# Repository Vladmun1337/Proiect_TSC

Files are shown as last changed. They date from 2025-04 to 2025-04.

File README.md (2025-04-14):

# Proiect TSC - Openbook e-book reader

Project link: https://ocw.cs.pub.ro/courses/tsc/proiect2025

## Introduction

For this project, I have implemented an open source e-book reader using ***Autodesk Fusion360***.
The architecture is based on an ESP32-C6 low power microcontroller (+ Wi-Fi & Bluetooth).

The display is using e-paper ink. The project supports micro SD reading through the specialized
interface and USB type C charging for a Polymer Lithium-Ion battery, prioritizing performance
and efficient power consumption.

## Diagram
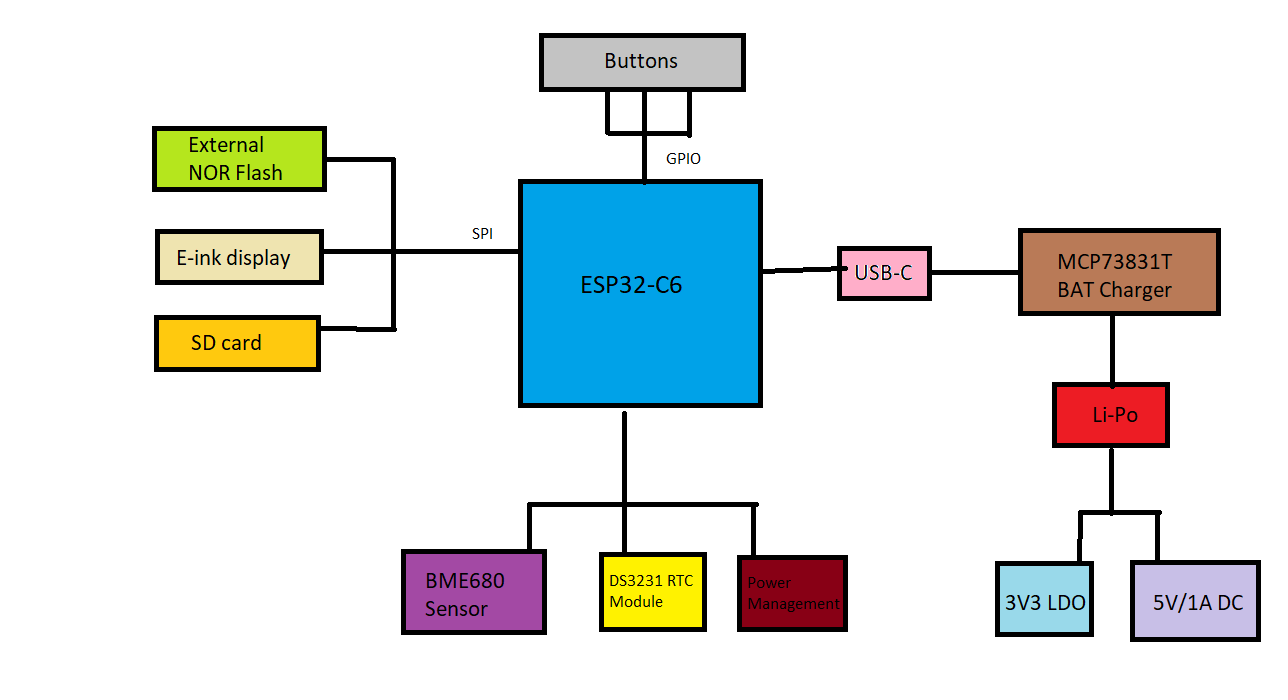
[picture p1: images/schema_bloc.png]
Diagram


## Contents

```
- hardware      -> .brd and .sch files of the board
- mechanical    -> .zip files of project's 3D models (standard and exploded view)
- Manufacturing -> Bill of Materials (BOM), Pick and Place (PnP), Gerber files (.zip)
- images        -> Snapshots of project
- LICENSE
- README.md
```

## Implementation & Workflow

1. **Implementation of the schematic**: The deskassistant library, offered by the lecture, was used. All components placed, linked and tagged
   for easier workflow in the PCB part.
2. **PCB**: Board was trimmed to fit specifications and accomodate busses. Components were then placed, respecting the DRC constraints file and routed
accordingly. Power(0.3mm) and data(0.15mm) lines were routed with different gauges and power routing was done mostly on top layer.
3. **3D Modelling**: All components were researched online and their specific 3D model was imported in the library. For a better grasp of the components used,
check BOM below. After the PCB was succesfully modelled, a battery and e-paper display were sketched from scratch.
4. **Fitting everything**: PCB, battery and display were fitted inside the given encasing and given a photoshoot. :-)

## Bill of Materials (with links)

| Name | Link | Datasheet |
|---|---|---|
| 112A-TAAR-R03 | [Link](https://store.comet.srl.ro/Catalogue/Product/43497/) | [Datasheet](https://store.comet.bg/download-file.php?id=27596) |
| 744043680 | [Link](https://eu.mouser.com/ProductDetail/Wurth-Elektronik/744043680?qs=PGXP4M47uW6VkZq%252BkzjrHA%3D%3D) | [Datasheet](https://www.we-online.com/components/products/datasheet/744043680.pdf) |
| BD5229G-TR | [Link](https://componentsearchengine.com/part-view/BD5229G-TR/ROHM%20Semiconductor) | [Datasheet](https://datasheet.datasheetarchive.com/originals/distributors/Datasheets_SAMA/f2b9741ef86007909f138d561a359946.pdf) |
| Button | [Link](https://industry.panasonic.com/global/en/products/control/switch/light-touch/number/evqpuj02k) | [Datasheet](https://industry.panasonic.com/global/en/downloads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) |
| Capacitor | [Link](https://componentsearchengine.com/part-view/CC0402MRX5R5BB106/YAGEO) | [Datasheet](https://componentsearchengine.com/Datasheets/2/CC0402MRX5R5BB106.pdf) |
| CPH3225A | [Link](https://www.snapeda.com/parts/CPH3225A/Seiko+Instruments/view-part/?ref=eda) | [Datasheet](https://www.snapeda.com/parts/CPH3225A/Seiko%20Instruments/datasheet/) |
| DS3231SN RTC | [Link](https://www.snapeda.com/parts/DS3231SN%23/Analog+Devices/view-part/?ref=eda) | [Datasheet](https://www.snapeda.com/parts/DS3231SN%23/Analog%20Devices/datasheet/) |
| ESP32 WROVER 0805 Capacitor | [Link](https://ro.mouser.com/ProductDetail/KYOCERA-AVX/SD0805S020S1R0?qs=jCA%252BPfw4LHbpkAoSnwrdjw%3D%3D) | [Datasheet](https://ro.mouser.com/datasheet/2/40/schottky-3165252.pdf) |
| ESP32 WROVER BME680 Sensor | [Link](https://www.snapeda.com/parts/BME680/Bosch/view-part/?welcome=home) | [Datasheet](https://www.snapeda.com/parts/BME680/Bosch%20Sensortec/datasheet/) |
| ESP32 WROVER MCP73831 | [Link](https://eu.mouser.com/ProductDetail/Microchip-Technology/MCP73831T-2ACI-OT?qs=yUQqVecv4qvbBQBGbHx0Mw%3D%3D) | [Datasheet](https://eu.mouser.com/datasheet/2/268/MCP73831_Family_Data_Sheet_DS20001984H-3441711.pdf) |
| ESP32 WROVER P-Channel MOSFET | [Link](https://componentsearchengine.com/part-view/DMG2305UX-7/Diodes%20Incorporated) | [Datasheet](https://www.diodes.com//assets/Datasheets/DMG2305UX.pdf) |
| ESP32-C6 WROOM-1-N8 | [Link](https://www.snapeda.com/parts/ESP32-C6-WROOM-1-N8/Espressif+Systems/view-part/?ref=eda) | [Datasheet](https://www.snapeda.com/parts/ESP32-C6-WROOM-1-N8/Espressif%20Systems/datasheet/) |
| ESP32C6 Varistor 1812 | [Link](https://ro.mouser.com/ProductDetail/EPCOS-TDK/B72520T0350K062?qs=dEfas%2FXlABIszF52uu7vrg%3D%3D) | [Datasheet](https://www.tdk-electronics.tdk.com/inf/75/db/CTVS_14/Surge_protection_series.pdf) |
| FH34SRJ-24S-0.5SH Connector | [Link](https://componentsearchengine.com/part-view/FH34SRJ-24S-0.5SH(99)/Hirose) | [Datasheet](https://www.hirose.com/en/product/document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) |
| LED 0603 | [Link](https://www.snapeda.com/parts/KP-1608SURCK/Kingbright/view-part/?ref=search&t=LED%200603) | [Datasheet](https://www.snapeda.com/parts/KP-1608SURCK/Kingbright/datasheet/) |
| LTSPICE Resistor 0402 | [Link](https://componentsearchengine.com/part-view/R0402%201%25%20100%20K%20(RC0402FR-07100KL)/YAGEO) | [Datasheet](https://www.yageo.com/upload/media/product/products/datasheet/rchip/PYu-RC_Group_51_RoHS_L_12.pdf) |
| MAX17048G+T10 | [Link](https://www.snapeda.com/parts/MAX17048G+T10/Analog+Devices/view-part/?ref=eda) | [Datasheet](https://www.snapeda.com/parts/MAX17048G+T10/Analog%20Devices/datasheet/) |
| MBR0530 Schottky | [Link](https://www.snapeda.com/parts/MBR0530/Onsemi/view-part/?ref=eda) | [Datasheet](https://www.snapeda.com/parts/MBR0530/ON%20Semiconductor/datasheet/) |
| PGB1010603MR | [Link](https://www.snapeda.com/parts/PGB1010603MR/Littelfuse/view-part/?ref=eda) | [Datasheet](https://www.snapeda.com/parts/PGB1010603MR/Littelfuse%20Inc./datasheet/) |
| QWIIC Connector | [Link](https://eu.mouser.com/ProductDetail/Adafruit/4208?qs=PzGy0jfpSMtbScLbr0L5dw%3D%3D) | [Datasheet](https://www.youtube.com/watch?v=dQw4w9WgXcQ) |
| RCL CPOL 3528 | [Link](https://www.snapeda.com/parts/TAJB475K025RNJ/AVX/view-part/?ref=dk&t=capacitor%203528&con_ref=None) | [Datasheet](https://s3.amazonaws.com/snapeda/datasheet/TAJB475K025RNJ_AVX.pdf) |
| SI1308EDL-T1-GE3 MOSFET | [Link](https://www.snapeda.com/parts/SI1308EDL-T1-GE3/Vishay+Siliconix/view-part/?ref=eda) | [Datasheet](https://www.youtube.com/watch?v=dQw4w9WgXcQ) |
| SJ | [Link](https://grabcad.com/library/solder-jumpers-1) | [Datasheet](https://www.youtube.com/watch?v=dQw4w9WgXcQ) |
| TPTP20R | [Link](https://easyeda.com/component/7524403feb2642ac9f9f26dfb93ceacf) | [Datasheet](https://easyeda.com/component/7524403feb2642ac9f9f26dfb93ceacf) |
| USB4110-GF-A USB | [Link](https://componentsearchengine.com/part-view/USB4110-GF-A/GCT%20(GLOBAL%20CONNECTOR%20TECHNOLOGY)) | [Datasheet](https://gct.co/files/drawings/usb4110.pdf) |
| USBLC6-2SC6Y USB | [Link](https://www.snapeda.com/parts/USBLC6-2SC6Y/STMicroelectronics/view-part/?ref=eda) | [Datasheet](https://www.snapeda.com/parts/USBLC6-2SC6Y/STMicroelectronics/datasheet/) |
| W25Q512JVEIQ Flash | [Link](https://www.snapeda.com/parts/W25Q512JVEIQ/Winbond+Electronics/view-part/?ref=eda) | [Datasheet](https://www.snapeda.com/parts/W25Q512JVEIQ/Winbond%20Electronics/datasheet/) |
| XC6220A331MR-G Voltage Regulator | [Link](https://componentsearchengine.com/part-view/XC6220A331MR-G/Torex) | [Datasheet](https://product.torexsemi.com/system/files/series/xc6220.pdf) |

## ESP32-C6 Pinout

An overview of how the ESP32-C6 pins are assigned within the system, grouped by function.

### Power
- **3V3 (Pin 2 & Top Right):** 3.3V supply for ESP32 and peripherals.
- **GND (Bottom Right):** Common ground.

### Boot and Reset
- **GPIO8 (Pin 15):** Boot mode selection, pulled low via 10KΩ.
- **RESET (Pin 3):** Manual reset input.

### SPI (E-Paper Display, SD Card, Flash)
- **MISO (Pin 27)**
- **MOSI (Pin 10)**
- **SCK (Pin 7)**
- **SS_SD (Pin 4):** Chip Select for SD card or other SPI device.
- **EPD_CS (Pin 11):** Chip Select for E-Paper Display.
- **FLASH_CS (Pin 12):** Chip Select for NOR Flash.

### E-Paper Display Control
- **EPD_BUSY (Pin 26)**
- **EPD_DC (Pin 5)**
- **EPD_RST (Pin 21)**
- **EPD_3V3_C (Pin 19):** Likely power enable/control.

### I2C (RTC & Sensors)
- **SDA (Pin 20)**
- **SCL (Pin 21)**
- **I2C_PW (Pin 18):** Power enable for I2C devices.
- **INT_RTC (Pin 8):** RTC interrupt.
- **RTC_RST (Pin 16)**

### USB
- **USB_D- (Pin 13)**
- **USB_D+ (Pin 14)**

### UART
- **TX (Pin 25)**
- **RX (Pin 24)**

### Other GPIO
- **IO_CHANGE (Pin 23):** Interrupt or status input/output.

## Total Power Consumption Overview

In a typical operating scenario—where the ESP32-C6 remains active with Wi-Fi enabled, the e-paper display refreshes every 10 seconds, and the BME688 sensor continuously collects environmental data—the estimated current draw for the system is as follows:

| Component | Estimated Consumption (mA) |
|---|---|
| ESP32-C6 (Wi-Fi enabled) | 200 mA |
| E-Paper Display (during update) | 40 mA |
| BME688 Sensor (continuous use) | 2 mA |
| Real-Time Clock (RTC) Module | 2 mA |
| SD Card (active use) | 12 mA |
| External NOR Flash Memory | 25 mA |

### Typical Total Current Draw

**Total: 281 mA**

This estimate represents a high-activity configuration. In lower-power modes (e.g., sleep or deep sleep), consumption can be significantly reduced.

## Conclusions

This project was very exciting for me. A lot of difficulties came from me having little to no prior experience with the autodesk suite, but everything sorted
itself out. I feel that I could get a good grasp of what working in the hardware and product industry means and am open to work on more other such projects! :-)

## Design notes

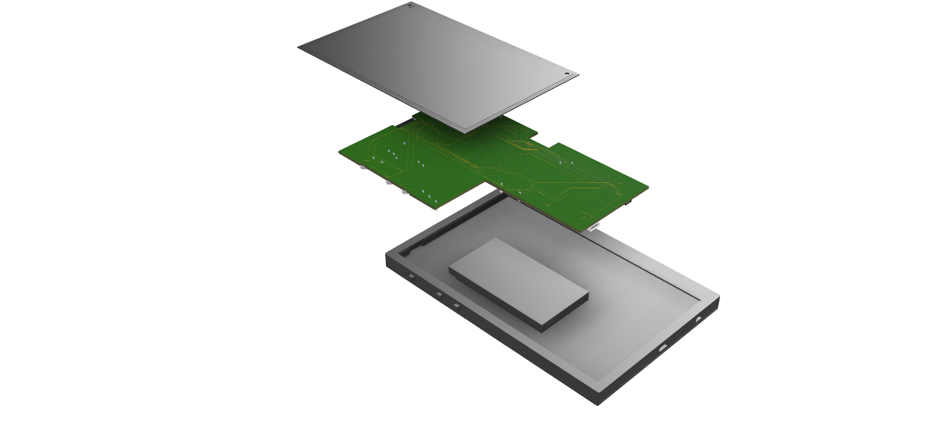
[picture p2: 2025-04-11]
images/openbook_exploded_full.png

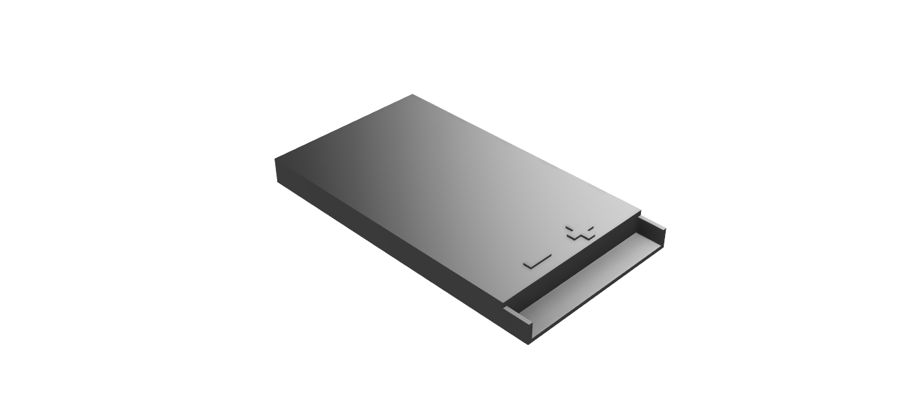
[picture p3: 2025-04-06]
images/battery.png

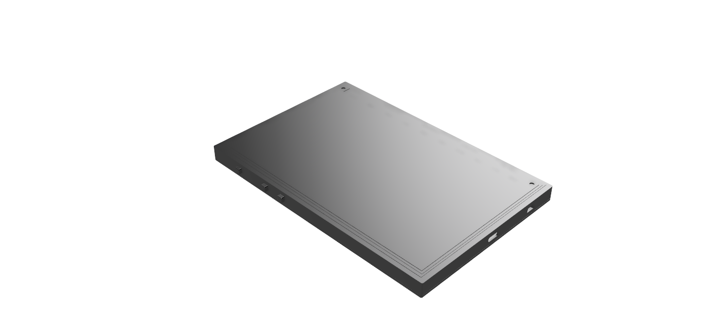
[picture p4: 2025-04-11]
images/openbook_full_3D.png

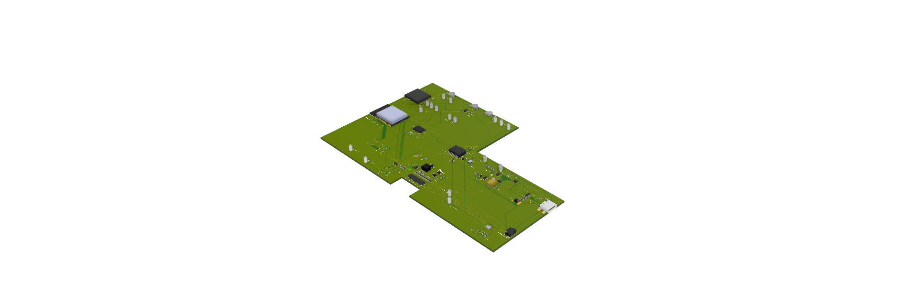
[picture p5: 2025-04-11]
images/3D_Board.png

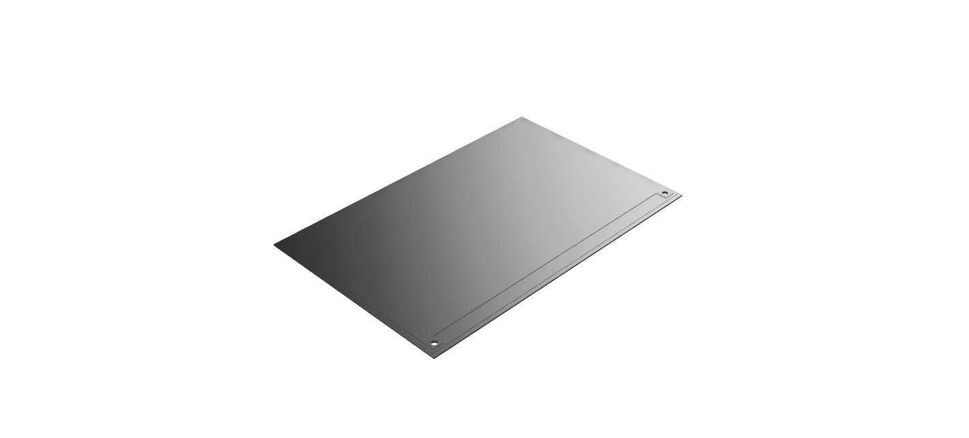
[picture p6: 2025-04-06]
images/display.png

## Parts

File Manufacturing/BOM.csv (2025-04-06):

Qty | Value | Device | Package | Parts | Description | ARROW_PART_NUMBER | ARROW_PRICE-STOCK | AVAILABILITY | CENTROID_NOT_SPECIFIED | CHECK_PRICES | COPYRIGHT | DATASHEET | DESCRIPTION | DIGIKEY_DESCRIPTION | DIGIKEY_PART_NUMBER | HEIGHT | LEAD_FREE | MANUFACTURER_NAME | MANUFACTURER_PART_NUMBER | MF | MFR_NAME | MOUSER_PART_NUMBER | MOUSER_PRICE-STOCK | MOUSER_TESTING_PART_NUMBER | MOUSER_TESTING_PRICE-STOCK | MP | MPN | PACKAGE | POPULARITY | PREFIX | PRICE | PROD_ID | PURCHASE-URL | ROHS | SNAPEDA_LINK | SPICEMODEL | SPICEPREFIX | TEMPERATURE_RANGE_HIGH | TEMPERATURE_RANGE_LOW | TP_SIGNAL_NAME | VALUE
1 |  | ADAFRUIT_LEDCHIP-LED0603 | ADAFRUIT_CHIP-LED0603 | LED1 | LED
1 |  | SJ | SJ | SJ1 | SMD solder JUMPER |  |  |  |  |  |  |  |  |  |  |  |  |  |  |  |  |  |  |  |  |  |  |  | 3
1 | 0.1uF/50V | EAGLE-LTSPICE_CC0402 | EAGLE-LTSPICE_C0402 | C13 | CAPACITOR, European symbol |  |  |  |  |  |  |  |  |  |  |  |  |  |  |  |  |  |  |  |  |  |  |  |  |  |  |  |  |  |  | NONE | C
1 | 0.47 | ESP32_WROVER_EAGLE-LTSPICE_RR0402 | ESP32_WROVER_EAGLE-LTSPICE_R0402 | R9 | RESISTOR, European symbol |  |  |  |  |  |  |  |  |  |  |  |  |  |  |  |  |  |  |  |  |  |  |  |  |  |  |  |  |  |  | NONE | R
1 | 100K | ESP32_WROVER_EAGLE-LTSPICE_RR0402 | ESP32_WROVER_EAGLE-LTSPICE_R0402 | R4 | RESISTOR, European symbol |  |  |  |  |  |  |  |  |  |  |  |  |  |  |  |  |  |  |  |  |  |  |  |  |  |  |  |  |  |  | NONE | R
8 | 100nF | EAGLE-LTSPICE_CC0402 | EAGLE-LTSPICE_C0402 | C1, C6, C21, C22, C23, C25, C27, C28 | CAPACITOR, European symbol |  |  |  |  |  |  |  |  |  |  |  |  |  |  |  |  |  |  |  |  |  |  |  |  |  |  |  |  |  |  | NONE | C
1 | 100uF | RCL_CPOL-EUCT3528 | RCL_CT3528 | C4 | POLARIZED CAPACITOR, European symbol |  |  |  |  |  |  |  |  |  |  |  |  |  |  |  |  |  |  |  |  |  |  |  | 0 |  |  |  |  |  |  |  | C
16 | 10K | ESP32_WROVER_EAGLE-LTSPICE_RR0402 | ESP32_WROVER_EAGLE-LTSPICE_R0402 | R6, R7, R8, R12, R13, R15, R16, R17, R18, R19, R26, R27, R28, R29, R30, R31 | RESISTOR, European symbol |  |  |  |  |  |  |  |  |  |  |  |  |  |  |  |  |  |  |  |  |  |  |  |  |  |  |  |  |  |  | NONE | R
1 | 10uF | EAGLE-LTSPICE_CC0402 | EAGLE-LTSPICE_C0402 | C8 | CAPACITOR, European symbol |  |  |  |  |  |  |  |  |  |  |  |  |  |  |  |  |  |  |  |  |  |  |  |  |  |  |  |  |  |  | NONE | C
1 | 112A-TAAR-R03_ATTEND | 112A-TAAR-R03_ATTEND | 112ATAARR03ATTEND | J2 | Micro SD Card Socket, Push-Push Type, Top Mount, SMT, H=1.83mm, 10u |  |  |  |  |  |  |  | Micro SD Card Socket | Push-Push Type | Top Mount | SMT | H=1.83mm | 10u |  |  | 1.9mm |  | ATTEND | 112A-TAAR-R03 ATTEND
1 | 15 | ESP32_WROVER_EAGLE-LTSPICE_RR0402 | ESP32_WROVER_EAGLE-LTSPICE_R0402 | R14 | RESISTOR, European symbol |  |  |  |  |  |  |  |  |  |  |  |  |  |  |  |  |  |  |  |  |  |  |  |  |  |  |  |  |  |  | NONE | R
1 | 1uF | EAGLE-LTSPICE_CC0402 | EAGLE-LTSPICE_C0402 | C26 | CAPACITOR, European symbol |  |  |  |  |  |  |  |  |  |  |  |  |  |  |  |  |  |  |  |  |  |  |  |  |  |  |  |  |  |  | NONE | C
9 | 1uF/50V | EAGLE-LTSPICE_CC0402 | EAGLE-LTSPICE_C0402 | C11, C12, C14, C15, C16, C17, C18, C19, C20 | CAPACITOR, European symbol |  |  |  |  |  |  |  |  |  |  |  |  |  |  |  |  |  |  |  |  |  |  |  |  |  |  |  |  |  |  | NONE | C
1 | 2.2 | ESP32_WROVER_EAGLE-LTSPICE_RR0402 | ESP32_WROVER_EAGLE-LTSPICE_R0402 | R5 | RESISTOR, European symbol |  |  |  |  |  |  |  |  |  |  |  |  |  |  |  |  |  |  |  |  |  |  |  |  |  |  |  |  |  |  | NONE | R
1 | 200 | ESP32_WROVER_EAGLE-LTSPICE_RR0402 | ESP32_WROVER_EAGLE-LTSPICE_R0402 | R10 | RESISTOR, European symbol |  |  |  |  |  |  |  |  |  |  |  |  |  |  |  |  |  |  |  |  |  |  |  |  |  |  |  |  |  |  | NONE | R
3 | 20V/4.2A/52mO/1.4W | ESP32_WROVER_SPARKFUN-DISCRETESEMI_MOSFET_PCH-DMG2305UX-7 | ESP32_WROVER_SPARKFUN-DISCRETESEMI_SOT23-3 | Q1, Q2, Q3 | P-channel MOSFETs |  |  |  |  |  |  |  |  |  |  |  |  |  |  |  |  |  |  |  |  |  |  |  |  |  |  | TRAN-14388 |  |  |  |  |  |  |  |  | 20V/4.2A/52mO/1.4W
1 | 2K | ESP32_WROVER_EAGLE-LTSPICE_RR0402 | ESP32_WROVER_EAGLE-LTSPICE_R0402 | R11 | RESISTOR, European symbol |  |  |  |  |  |  |  |  |  |  |  |  |  |  |  |  |  |  |  |  |  |  |  |  |  |  |  |  |  |  | NONE | R
5 | 4.7uF | EAGLE-LTSPICE_CC0402 | EAGLE-LTSPICE_C0402 | C2, C3, C5, C9, C10 | CAPACITOR, European symbol |  |  |  |  |  |  |  |  |  |  |  |  |  |  |  |  |  |  |  |  |  |  |  |  |  |  |  |  |  |  | NONE | C
1 | 4.7uF/25V | EAGLE-LTSPICE_CC0402 | EAGLE-LTSPICE_C0402 | C7 | CAPACITOR, European symbol |  |  |  |  |  |  |  |  |  |  |  |  |  |  |  |  |  |  |  |  |  |  |  |  |  |  |  |  |  |  | NONE | C
2 | 5k1 | ESP32_WROVER_EAGLE-LTSPICE_RR0402 | ESP32_WROVER_EAGLE-LTSPICE_R0402 | R1, R3 | RESISTOR, European symbol |  |  |  |  |  |  |  |  |  |  |  |  |  |  |  |  |  |  |  |  |  |  |  |  |  |  |  |  |  |  | NONE | R
1 | 68uH | 744043680IND_4828-WE-TPC_WRE | IND_4828-WE-TPC_WRE | L1 |  |  |  |  |  |  | Copyright (C) 2024 Ultra Librarian. All rights reserved. |  |  |  |  |  |  |  | 744043680 |  | Wurth Electronics
1 | BD5229G-TR | BD5229G-TR | SOT95P280X125-5N | IC2 | Voltage Detector with Adjustable Delay Time: CMOS processes are utilized to develop high precision, low current consumption CMOS reset ICs that allow arbitrary setting of the delay time. The extensive lineup includes both Nch Open Drain and CMOS output types in a wide range of detection voltages (from 2.3V to 6.0V, in 0.1V steps), enabling selection of the ideal solution based on customer requirements. In addition, the entire series is of course both lead-free and RoHS-compliant. |  |  |  |  |  |  |  | Voltage Detector with Adjustable Delay Time: CMOS processes are utilized to develop high precision | low current consumption CMOS reset ICs that allow arbitrary setting of the delay time. The extensive lineup includes both Nch Open Drain and CMOS output types in a wide range of detection voltages (from 2.3V to 6.0V | in 0.1V steps) | enabling selection of the ideal solution based on customer requirements. In addition | the entire series is of course both lead-free and RoHS-compliant. |  |  | 1.25mm |  | ROHM Semiconductor | BD5229G-TR |  |  | 755-BD5229G-TR | https://www.mouser.co.uk/ProductDetail/ROHM-Semiconductor/BD5229G-TR?qs=4kLU8WoGk0vvnhrrYwdszw%3D%3D
3 | BUTTON_CUSYOMV1 | BUTTON_CUSYOMV1 | MYBUTTON | U$1, U$2, U$3
1 | CPH3225A | CPH3225A | CAPCP3225X100N | C24 | Cap 0.011F 3.3V 1210 Flat Check availability |  |  | Not in stock |  | https://www.snapeda.com/parts/CPH3225A/Seiko+Instruments/view-part/?ref=eda |  |  | 11 mF (EDLC) Supercapacitor 3.3 V 1210 (3225 Metric) - - |  |  |  |  |  |  | Seiko Instruments |  |  |  |  |  | CPH3225A |  | 1210 Seiko |  |  | None |  | https://www.snapeda.com/api/url_track_click_mouser/?unipart_id=562593&manufacturer=Seiko Instruments&part_name=CPH3225A&search_term=None |  | https://www.snapeda.com/parts/CPH3225A/Seiko+Instruments/view-part/?ref=snap
1 | DS3231SN# | DS3231SN# | SOIC127P1032X265-16N | U6 | Real Time Clock Serial 16-Pin SOIC W T/R Check availability |  |  | In Stock |  | https://www.snapeda.com/parts/DS3231SN%23/Analog+Devices/view-part/?ref=eda |  |  | Extremely Accurate I²C-Integrated RTC/TCXO/Crystal |  |  |  |  |  |  | Analog Devices |  |  |  |  |  | DS3231SN# |  | SOIC-16 Maxim |  |  | None |  | https://www.snapeda.com/api/url_track_click_mouser/?unipart_id=99048&manufacturer=Analog Devices&part_name=DS3231SN#&search_term=None |  | https://www.snapeda.com/parts/DS3231SN%23/Analog+Devices/view-part/?ref=snap
1 | ESP32-C6-WROOM-1-N8 | ESP32-C6-WROOM-1-N8 | XCVR_ESP32-C6-WROOM-1-N8 | U1 | Check availability |  |  | In Stock |  | https://www.snapeda.com/parts/ESP32-C6-WROOM-1-N8/Espressif+Systems/view-part/?ref=eda |  |  | Multiprotocol Modules ESP32-C6 module | Wi-Fi 6 in 2.4 GHz band | Bluetooth 5 | Zigbee 3.0 and Thread. ESP34-WROOM Compatible - ENGINEERING SAMPLE |  |  |  |  |  |  | Espressif Systems |  |  |  |  |  | ESP32-C6-WROOM-1-N8 |  | None |  |  | None |  |  |  | https://www.snapeda.com/parts/ESP32-C6-WROOM-1-N8/Espressif+Systems/view-part/?ref=snap
1 | ESP32C6_VARISTORCN1812 | ESP32C6_VARISTORCN1812 | ESP32C6_VARISTOR_CT/CN1812 | R2 | VARISTOR |  |  |  |  |  |  |  |  |  |  |  |  |  |  |  |  |  |  |  |  |  |  |  | 0
2 | ESP32_WROVER_AVX---SD0805S020S1R0_AVX_SD0805S020S1R0_0_0AVX_SD0805S020S1R0_0_0 | ESP32_WROVER_AVX---SD0805S020S1R0_AVX_SD0805S020S1R0_0_0AVX_SD0805S020S1R0_0_0 | ESP32_WROVER_AVX---SD0805S020S1R0_AVX_SD0805S020S1R0_0 | D2, D6 | Schottky Barrier Rectifier Diode |  |  |  | No |  |  | http://datasheets.avx.com/schottky.pdf |  | DIODE SCHOTTKY 20V 1A 0805 | 478-7800-1-ND |  | yes |  |  | AVX |  | 581-SD0805S020S1R0 |  |  |  |  |  | 0805 (2012 metric) |  | D |  |  |  | yes |  |  |  | +125°C | -55°C
1 | ESP32_WROVER_BME680_BME680 | ESP32_WROVER_BME680_BME680 | ESP32_WROVER_BME680_PSON80P300X300X100-8N | U5 | Integrated Environmental Unit |  |  | Unavailable |  |  |  |  | Integrated Environmental Unit |  |  |  |  |  |  | Bosch Sensortec |  |  |  |  |  | BME680 |  | LGA-8 Bosch Tools |  |  | None
1 | ESP32_WROVER_SPARKFUN-IC-POWER_MCP73831 | ESP32_WROVER_SPARKFUN-IC-POWER_MCP73831 | ESP32_WROVER_SPARKFUN-IC-POWER_SOT23-5 | U4 | MCP73831T Li-Ion, Li-Pol Controller |  |  |  |  |  |  |  |  |  |  |  |  |  |  |  |  |  |  |  |  |  |  |  |  |  |  | IC-09995
1 | FH34SRJ-24S-0.5SH_99_ | FH34SRJ-24S-0.5SH_99_ | FH34SRJ24S05SH99 | J4 | (0.50mm) Surface Mount, Right Angle |  |  |  |  |  |  |  | 24 Position FFC | FPC Connector Contacts | (0.50mm) Surface Mount | Right Angle |  |  | 1.1mm |  | Hirose | FH34SRJ-24S-0.5SH(99) |  |  | 798-FH34SRJ24S05SH99 | https://www.mouser.co.uk/ProductDetail/Hirose-Connector/FH34SRJ-24S-0.5SH99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
1 | MAX17048G+T10 | MAX17048G+T10 | SON50P200X200X80-9N | U2 | Check availability |  |  | In Stock |  | https://www.snapeda.com/parts/MAX17048G+T10/Analog+Devices/view-part/?ref=eda |  |  | 3µA 1-Cell/2-Cell Fuel Gauge with ModelGauge |  |  |  |  |  |  | Analog Devices |  |  |  |  |  | MAX17048G+T10 |  | TDFN-8 Maxim |  |  | None |  | https://www.snapeda.com/api/url_track_click_mouser/?unipart_id=329239&manufacturer=Analog Devices&part_name=MAX17048G+T10&search_term=None |  | https://www.snapeda.com/parts/MAX17048G+T10/Analog+Devices/view-part/?ref=snap
3 | MBR0530 | MBR0530 | SOD3716X135N | D3, D4, D5 | ON SEMICONDUCTOR - MBR0530 - DIODE, SCHOTTKY, 0.5A, 30V, SOD-123 |  |  | In Stock |  | https://www.snapeda.com/parts/MBR0530/Onsemi/view-part/?ref=eda |  |  | Diode Schottky 30 V 500mA Surface Mount SOD-123 |  |  |  |  |  |  | ON Semiconductor |  |  |  |  |  | MBR0530 |  | SOD-123-2 ON Semiconductor |  |  | None |  | https://www.snapeda.com/api/url_track_click_mouser/?unipart_id=179458&manufacturer=ON Semiconductor&part_name=MBR0530&search_term=None |  | https://www.snapeda.com/parts/MBR0530/Onsemi/view-part/?ref=snap
6 | PGB1010603MR | PGB1010603MR | DIOC1608X36N | D7, D8, D9, D10, D11, D12 | Check availability |  |  | In Stock |  | https://www.snapeda.com/parts/PGB1010603MR/Littelfuse/view-part/?ref=eda |  |  | 150V (Typ) Clamp - Ipp Tvs Diode Surface Mount 0603 (1608 Metric) |  |  |  |  |  |  | Littelfuse Inc. |  |  |  |  |  | PGB1010603MR |  | 0603 Littelfuse Inc. |  |  | None |  | https://www.snapeda.com/api/url_track_click_mouser/?unipart_id=5659453&manufacturer=Littelfuse Inc.&part_name=PGB1010603MR&search_term=None |  | https://www.snapeda.com/parts/PGB1010603MR/Littelfuse/view-part/?ref=snap
1 | QWIIC_RIGHT_ANGLE | QWIIC_CONNECTORJS-1MM | JST04_1MM_RA | J3 | SparkFun I2C Standard Qwiic Connector |  |  |  |  |  |  |  |  |  |  |  |  |  |  |  |  |  |  |  |  |  |  |  |  |  |  | CONN-13694 |  |  |  |  |  |  |  |  | QWIIC_RIGHT_ANGLE
1 | SAMACSYS_PARTS_USB4110-GF-A | SAMACSYS_PARTS_USB4110-GF-A | SAMACSYS_PARTS_USB4110GFA | J1 | CONN USB 2.0 TYPE-C R/A SMT |  |  |  |  |  |  |  | CONN USB 2.0 TYPE-C R/A SMT |  |  | 3.26mm |  | GCT (GLOBAL CONNECTOR TECHNOLOGY) | USB4110-GF-A |  |  | 640-USB4110-GF-A | https://www.mouser.co.uk/ProductDetail/GCT/USB4110-GF-A?qs=KUoIvG%2F9IlYiZvIXQjyJeA%3D%3D
17 | TPTP20R | TPTP20R | TP20R | TP1, TP2, TP3, TP4, TP5, TP6, TP7, TP8, TP9, TP10, TP11, TP12, TP13, TP14, TP15, TP16, TP17 | Test pad |  |  |  |  |  |  |  |  |  |  |  |  |  |  |  |  |  |  |  |  |  |  |  | 2
1 | USBLC6-2SC6Y | USBLC6-2SC6Y | SOT95P280X145-6N | D1 | Low Cap. ESD Protection Auto SOT-23-6 STMicroelectronics USBLC6-2SC6Y, Dual Uni-Directional TVS Diode Array, 6-Pin SOT-23 |  |  | In Stock |  | https://www.snapeda.com/parts/USBLC6-2SC6Y/STMicroelectronics/view-part/?ref=eda |  |  | 17V Clamp 5A (8/20µs) Ipp Tvs Diode Surface Mount SOT-23-6 |  |  |  |  |  |  | STMicroelectronics |  |  |  |  |  | USBLC6-2SC6Y |  | SOT-23-6 STMicroelectronics |  |  | None |  |  |  | https://www.snapeda.com/parts/USBLC6-2SC6Y/STMicroelectronics/view-part/?ref=snap
1 | W25Q512JVEIQ | W25Q512JVEIQ | SON127P600X800X80-9N | U3 | Check availability |  |  | In Stock |  | https://www.snapeda.com/parts/W25Q512JVEIQ/Winbond+Electronics/view-part/?ref=eda |  |  | FLASH - NOR Memory IC 512Mb (64M x 8) SPI - Quad I/O 133 MHz 8-WSON (8x6) |  |  |  |  |  |  | Winbond Electronics |  |  |  |  |  | W25Q512JVEIQ |  | Package |  |  | None |  |  |  | https://www.snapeda.com/parts/W25Q512JVEIQ/Winbond+Electronics/view-part/?ref=snap
1 | XC6220A331MR-G | XC6220A331MR-G | SOT95P280X120-5N | IC1 | LDO Voltage Regulators |  |  |  |  |  |  |  | LDO Voltage Regulators |  |  | 1.2mm |  | Torex | XC6220A331MR-G |  |  | 865-XC6220A331MR-G | https://www.mouser.co.uk/ProductDetail/Torex-Semiconductor/XC6220A331MR-G?qs=AsjdqWjXhJ8ZSWznL1J0gg%3D%3D

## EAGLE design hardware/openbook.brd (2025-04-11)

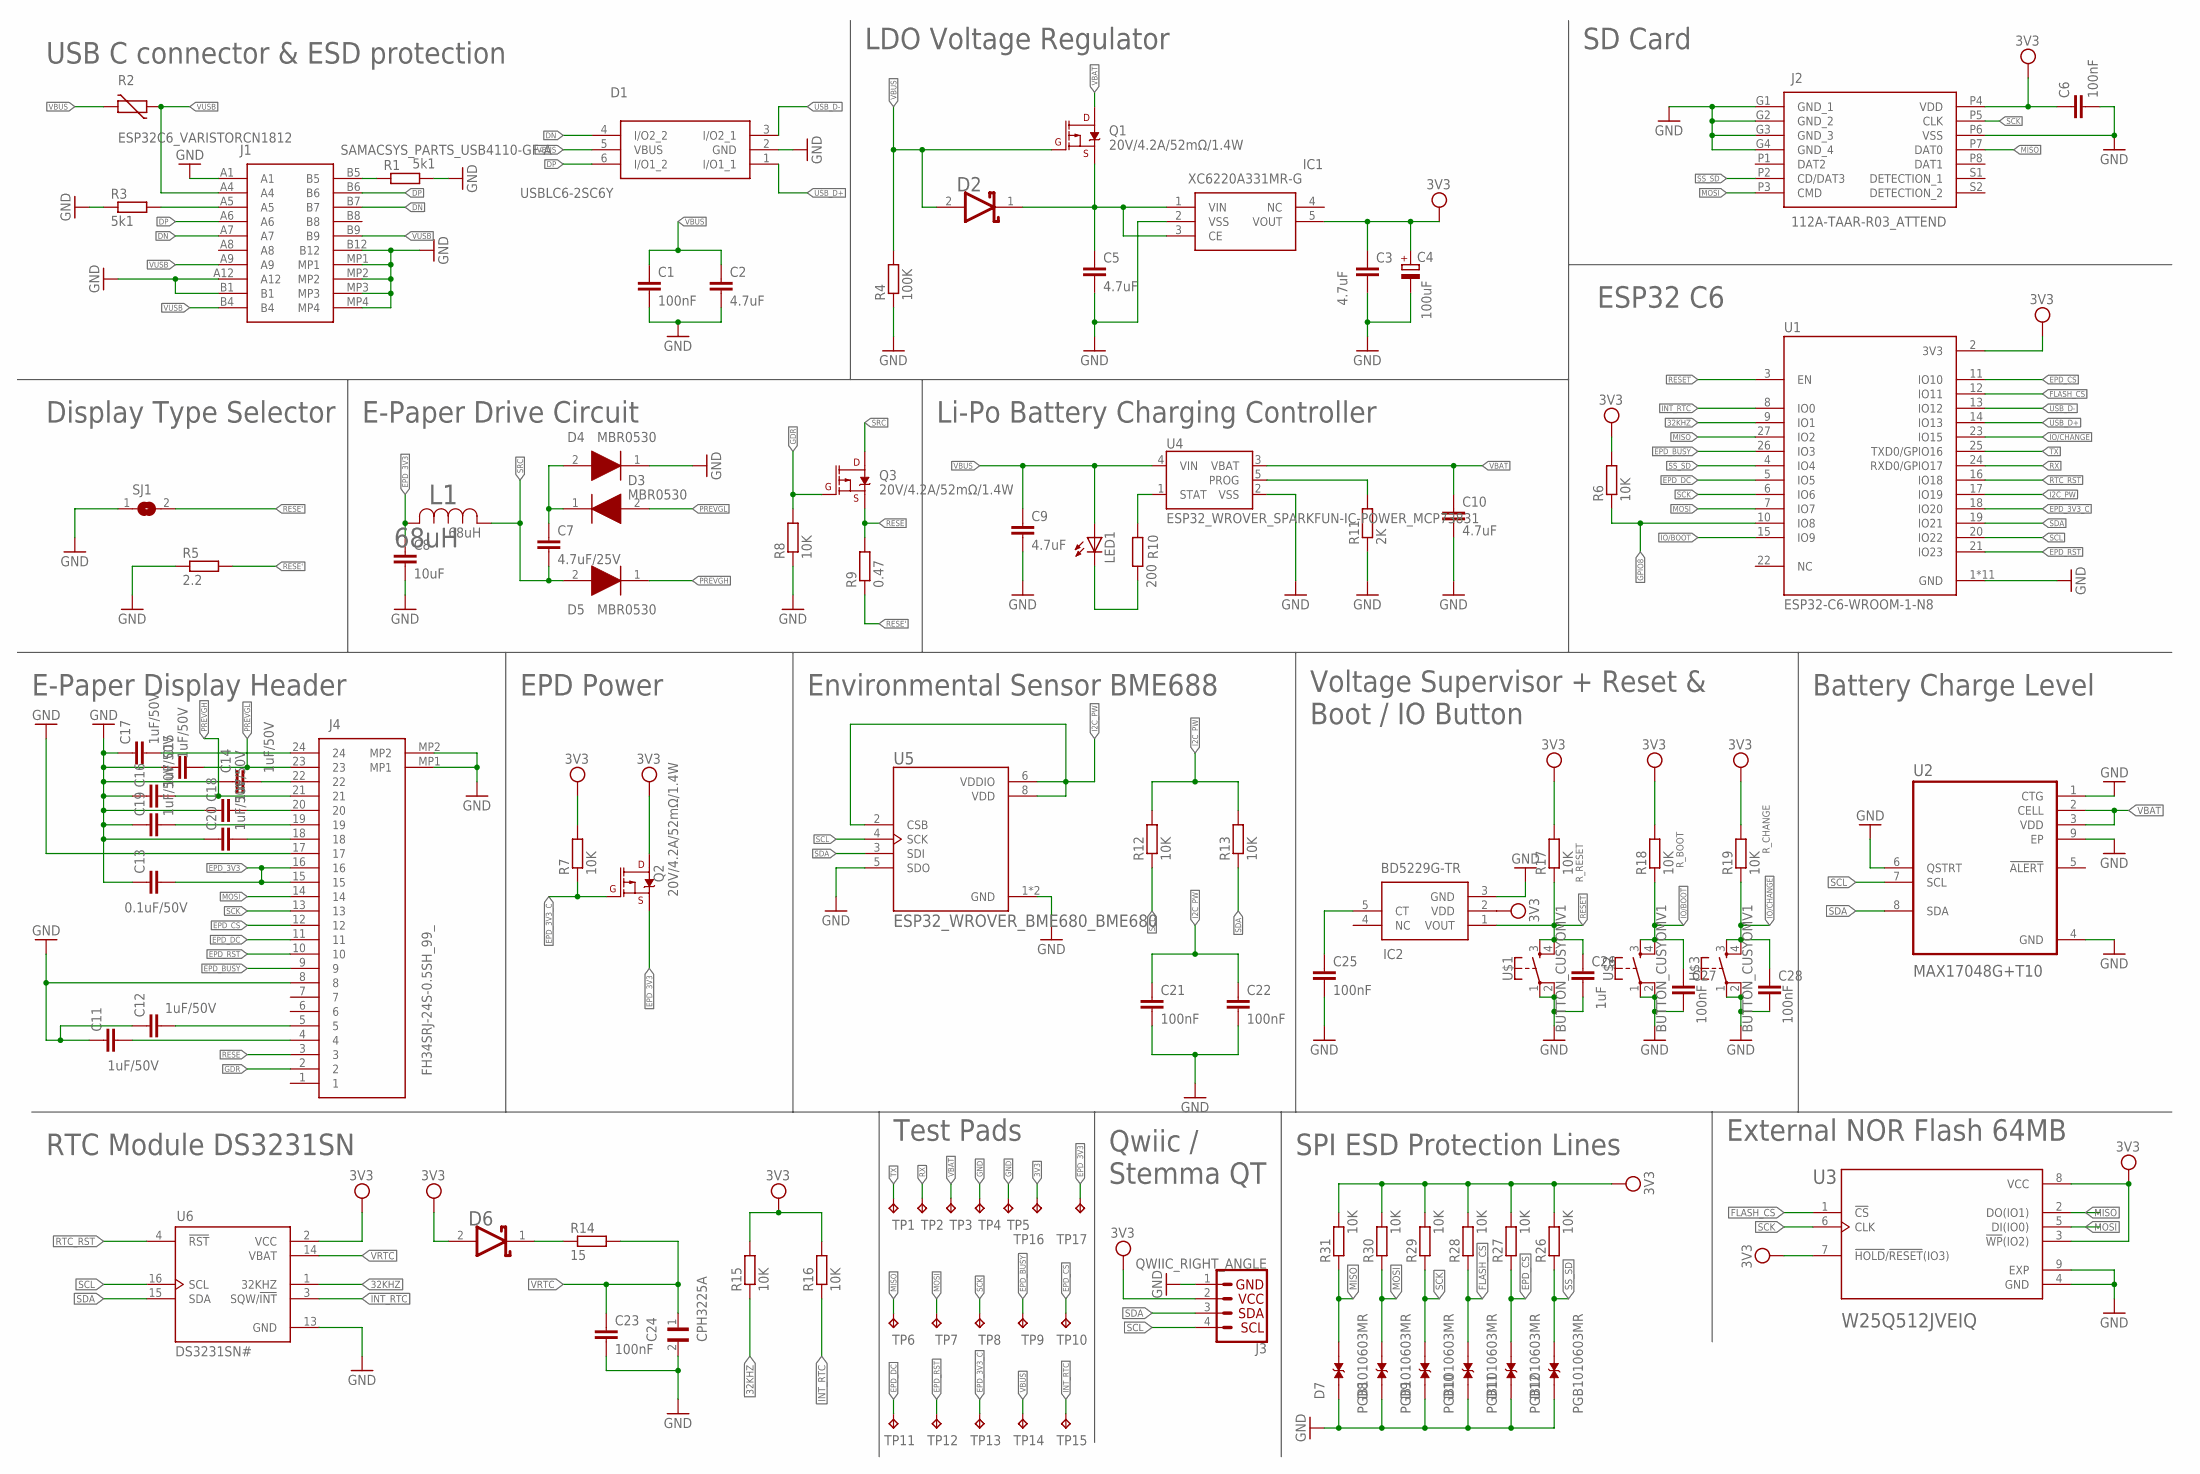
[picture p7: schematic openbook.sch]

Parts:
C1, C6, C21, C22, C23, C25, C27, C28: 100nF; EAGLE-LTSPICE_C0402
C2, C3, C5, C9, C10: 4.7uF; EAGLE-LTSPICE_C0402
C4: 100uF; RCL_CT3528
C7: 4.7uF/25V; EAGLE-LTSPICE_C0402
C8: 10uF; EAGLE-LTSPICE_C0402
C11, C12, C14, C15, C16, C17, C18, C19, C20: 1uF/50V; EAGLE-LTSPICE_C0402
C13: 0.1uF/50V; EAGLE-LTSPICE_C0402
C24: CPH3225A; CAPCP3225X100N
C26: 1uF; EAGLE-LTSPICE_C0402
D1: USBLC6-2SC6Y; SOT95P280X145-6N
D2, D6: ESP32_WROVER_AVX---SD0805S020S1R0_AVX_SD0805S020S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; ESP32_WROVER_AVX---SD0805S020S1R0_AVX_SD0805S020S1R0_0
D3, D4, D5: MBR0530; SOD3716X135N
D7, D8, D9, D10, D11, D12: PGB1010603MR; DIOC1608X36N
IC1: XC6220A331MR-G; SOT95P280X120-5N
IC2: BD5229G-TR; SOT95P280X125-5N
J1: SAMACSYS_PARTS_USB4110-GF-A; SAMACSYS_PARTS_USB4110GFA
J2: 112A-TAAR-R03_ATTEND; 112ATAARR03ATTEND
J3: QWIIC_RIGHT_ANGLE; JST04_1MM_RA
J4: FH34SRJ-24S-0.5SH_99_; FH34SRJ24S05SH99
L1: 68uH; IND_4828-WE-TPC_WRE
LED1: ADAFRUIT_LEDCHIP-LED0603; ADAFRUIT_CHIP-LED0603
Q1, Q2, Q3: 20V/4.2A/52mΩ/1.4W; ESP32_WROVER_SPARKFUN-DISCRETESEMI_SOT23-3
R1, R3: 5k1; ESP32_WROVER_EAGLE-LTSPICE_R0402
R2: ESP32C6_VARISTORCN1812; ESP32C6_VARISTOR_CT/CN1812
R4: 100K; ESP32_WROVER_EAGLE-LTSPICE_R0402
R5: 2.2; ESP32_WROVER_EAGLE-LTSPICE_R0402
R6, R7, R8, R12, R13, R15, R16, R17, R18, R19, R26, R27, R28, R29, R30, R31: 10K; ESP32_WROVER_EAGLE-LTSPICE_R0402
R9: 0.47; ESP32_WROVER_EAGLE-LTSPICE_R0402
R10: 200; ESP32_WROVER_EAGLE-LTSPICE_R0402
R11: 2K; ESP32_WROVER_EAGLE-LTSPICE_R0402
R14: 15; ESP32_WROVER_EAGLE-LTSPICE_R0402
SJ1: SJ
TP1, TP2, TP3, TP4, TP5, TP6, TP7, TP8, TP9, TP10, TP11, TP12, TP13, TP14, TP15, TP16, TP17: TPTP20R; TP20R
U1: ESP32-C6-WROOM-1-N8; XCVR_ESP32-C6-WROOM-1-N8
U2: MAX17048G+T10; SON50P200X200X80-9N
U3: W25Q512JVEIQ; SON127P600X800X80-9N
U4: ESP32_WROVER_SPARKFUN-IC-POWER_MCP73831; ESP32_WROVER_SPARKFUN-IC-POWER_SOT23-5
U5: ESP32_WROVER_BME680_BME680; ESP32_WROVER_BME680_PSON80P300X300X100-8N
U6: DS3231SN#; SOIC127P1032X265-16N
U$1, U$2, U$3: BUTTON_CUSYOMV1; MYBUTTON

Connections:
3V3: C3.1, C4.+, C6.1, D6.2 (ANODE), IC1.5 (VOUT), IC2.2 (VDD), J2.P4 (VDD), J3.2, Q2.3 (D), R6.2, R7.2, R15.2, R16.2, R17.2, R18.2, R19.2, R26.2, R27.2, R28.2, R29.2, R30.2, R31.2, TP16.TP, U1.2 (3V3), U3.3 (!WP!(IO2)), U3.7 (!HOLD!/!RESET!(IO3)), U3.8 (VCC), U6.2 (VCC)
32KHZ: R15.1, U1.9 (IO1), U6.1 (32KHZ)
DN: D1.4 (I/O2_2), J1.A7, J1.B7
DP: D1.6 (I/O1_2), J1.A6, J1.B6
EPD_3V3: C8.1, C13.2, J4.15, J4.16, L1.2, Q2.2 (S), TP17.TP
EPD_3V3_C: Q2.1 (G), R7.1, TP13.TP, U1.18 (IO20)
EPD_BUSY: J4.9, TP9.TP, U1.26 (IO3)
EPD_CS: D11.2, J4.12, R27.1, TP10.TP, U1.11 (IO10)
EPD_DC: J4.11, TP11.TP, U1.5 (IO5)
EPD_RST: J4.10, TP12.TP, U1.21 (IO23)
FLASH_CS: D10.2, R28.1, U1.12 (IO11), U3.1 (!CS)
GDR: J4.2, Q3.1 (G), R8.2
GND: C1.2, C2.2, C3.2, C4.-, C5.2, C6.2, C8.2, C9.2, C10.2, C11.1, C12.1, C13.1, C14.1, C15.1, C16.1, C17.1, C18.1, C19.1, C20.1, C21.2, C22.2, C23.2, C24.2, C25.2, C26.2, C27.2, C28.2, D1.2 (GND), D4.1 (K), D7.1, D8.1, D9.1, D10.1, D11.1, D12.1, IC1.2 (VSS), IC2.3 (GND), J1.A1, J1.A12, J1.B1, J1.B12, J1.MP1, J1.MP2, J1.MP3, J1.MP4, J2.G1 (GND_1), J2.G2 (GND_2), J2.G3 (GND_3), J2.G4 (GND_4), J2.P6 (VSS), J3.1, J4.8, J4.17, J4.MP1, J4.MP2, R1.2, R3.1, R4.1, R5.1, R8.1, R11.1, SJ1.1, TP4.TP, TP5.TP, U1.1 (GND), U1.28 (GND), U1.29_1 (GND), U1.29_2 (GND), U1.29_3 (GND), U1.29_4 (GND), U1.29_5 (GND), U1.29_6 (GND), U1.29_7 (GND), U1.29_8 (GND), U1.29_9 (GND), U2.1 (CTG), U2.4 (GND), U2.6 (QSTRT), U2.9 (EP), U3.4 (GND), U3.9 (EXP), U4.2 (VSS), U5.1 (GND), U5.5 (SDO), U5.7 (GND), U6.13 (GND), U$1.1, U$1.2, U$2.1, U$2.2, U$3.1, U$3.2
GPIO8: R6.1, U1.10 (IO8)
I2C_PW: C21.1, C22.1, R12.2, R13.2, U1.17 (IO19), U5.2 (CSB), U5.6 (VDDIO), U5.8 (VDD)
INT_RTC: R16.1, TP15.TP, U1.8 (IO0), U6.3 (SQW/!INT)
IO/BOOT: C27.1, R18.1, U1.15 (IO9), U$2.3, U$2.4
IO/CHANGE: C28.1, R19.1, U1.23 (IO15), U$3.3, U$3.4
MISO: D7.2, J2.P7 (DAT0), R31.1, TP6.TP, U1.27 (IO2), U3.2 (DO(IO1))
MOSI: D8.2, J2.P3 (CMD), J4.14, R30.1, TP7.TP, U1.7 (IO7), U3.5 (DI(IO0))
unnamed: D6.1 (CATHODE), R14.1
unnamed: J1.B5, R1.1
unnamed: J1.A5, R3.2
unnamed: C5.1, D2.1 (CATHODE), IC1.1 (VIN), IC1.3 (CE), Q1.2 (S)
unnamed: C7.1, D3.1 (K), D4.2 (A)
unnamed: LED1.C, R10.1
unnamed: R10.2, U4.1 (STAT)
unnamed: R11.2, U4.5 (PROG)
unnamed: C11.2, J4.4
unnamed: C12.2, J4.5
unnamed: C20.2, J4.18
unnamed: C19.2, J4.19
unnamed: C18.2, J4.20
unnamed: C14.2, J4.22
unnamed: C17.2, J4.24
unnamed: C25.1, IC2.5 (CT)
PREVGH: C16.2, D5.1 (K), J4.21
PREVGL: C15.2, D3.2 (A), J4.23
RESE: J4.3, Q3.2 (S), R9.2
RESE': R5.2, R9.1, SJ1.2
RESET: C26.1, IC2.1 (VOUT), R17.1, U1.3 (EN), U$1.3, U$1.4
RTC_RST: U1.16 (IO18), U6.4 (!RST)
RX: TP2.TP, U1.24 (RXD0/GPIO17)
SCK: D9.2, J2.P5 (CLK), J4.13, R29.1, TP8.TP, U1.6 (IO6), U3.6 (CLK)
SCL: J3.4, R12.1, U1.20 (IO22), U2.7 (SCL), U5.4 (SCK), U6.16 (SCL)
SDA: J3.3, R13.1, U1.19 (IO21), U2.8 (SDA), U5.3 (SDI), U6.15 (SDA)
SRC: C7.2, D5.2 (A), L1.1, Q3.3 (D)
SS_SD: D12.2, J2.P2 (CD/DAT3), R26.1, U1.4 (IO4)
TX: TP1.TP, U1.25 (TXD0/GPIO16)
USB_D+: D1.1 (I/O1_1), U1.14 (IO13)
USB_D-: D1.3 (I/O2_1), U1.13 (IO12)
VBAT: C10.1, Q1.3 (D), TP3.TP, U2.2 (CELL), U2.3 (VDD), U4.3 (VBAT)
VBUS: C1.1, C2.1, C9.1, D1.5 (VBUS), D2.2 (ANODE), LED1.A, Q1.1 (G), R2.2, R4.2, TP14.TP, U4.4 (VIN)
VRTC: C23.1, C24.1, R14.2, U6.14 (VBAT)
VUSB: J1.A4, J1.A9, J1.B4, J1.B9, R2.1

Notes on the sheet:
USB C connector & ESD protection
LDO Voltage Regulator
SD Card
Display Type Selector
E-Paper Drive Circuit
Li-Po Battery Charging Controller
ESP32 C6
E-Paper Display Header
RTC Module DS3231SN
EPD Power
Environmental Sensor BME688
Test Pads
Qwiic / Stemma QT
Voltage Supervisor + Reset & Boot / IO Button
SPI ESD Protection Lines
Battery Charge Level
External NOR Flash 64MB
68uH
R_RESET
R_BOOT
R_CHANGE

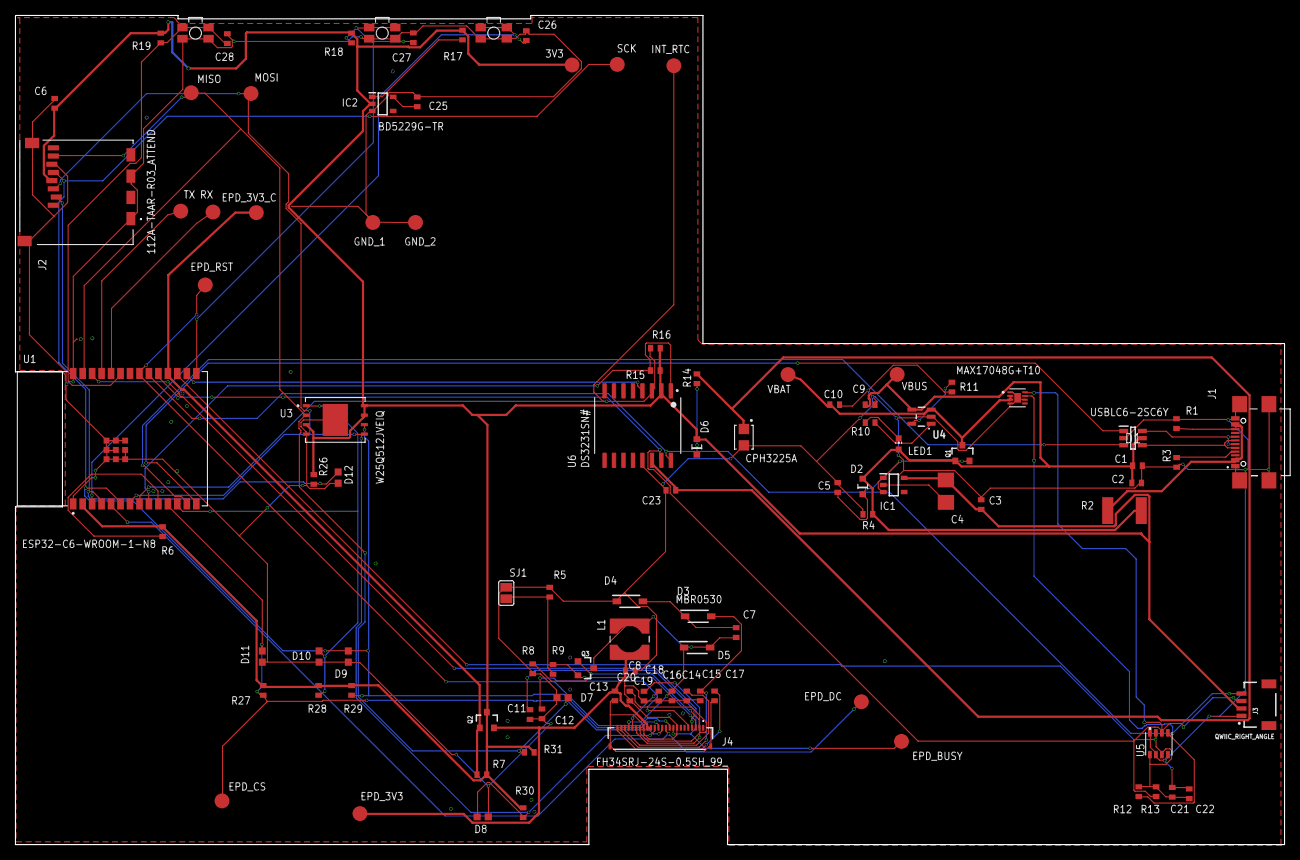
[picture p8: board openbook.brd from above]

Board: 2 copper layers, 170.2 x 111.2 mm, 103 parts (0 on the bottom side), 55 nets.

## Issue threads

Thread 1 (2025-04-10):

schematic errors

iTudy137, 2025-04-10:
Fix the following errors in the .sch file:

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

Closed 2025-04-10.

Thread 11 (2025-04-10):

readme missing information

iTudy137, 2025-04-10:
The README is missing a detailed description of:
-> the hardware functionality, interfaces, component specifications, and power consumption calculations.
-> the ESP32-C6 pin assignments for each component and the reasoning behind their selection.

Closed 2025-04-14.

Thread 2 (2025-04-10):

board errors

iTudy137, 2025-04-10:
Fix buttons alignment to not go over the edge

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

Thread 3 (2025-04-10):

component layout

iTudy137, 2025-04-10:
FIx the position of the SD card reader

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

Here is the correct alignment for reference (notice where the measurement ends):
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

Vladmun1337, 2025-04-11:
Thank you for the heads up! The SD card reader, although off by < 1 mm, still fits perfectly in the enclosure. Thank you!

Closed 2025-04-11.

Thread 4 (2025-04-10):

component orientation

iTudy137, 2025-04-10:
Make sure the diodes have the correct orientation:
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

Vladmun1337, 2025-04-10:
The wiring is done so that the diodes function correctly. The physical orientation does not influence the functionality. Thank you!

Closed 2025-04-10.

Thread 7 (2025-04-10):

testpad silkscreen

iTudy137, 2025-04-10:
Testpads should have the name of their signal marked on the silkscreen.

Vladmun1337, 2025-04-11:
I have added all testpad names to the board's silkscreen. Thank you!

Closed 2025-04-11.

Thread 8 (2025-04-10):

board thickness

iTudy137, 2025-04-10:
You should modify the thickness of your PCB to 1mm.

Vladmun1337, 2025-04-11:
Board thickness was tweaked to respect the 1mm constraint. Thank you!

Closed 2025-04-11.

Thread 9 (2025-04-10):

silkscreen overlaps

iTudy137, 2025-04-10:
Component names on the silkscreen layer are overlapping with routes.

Consult these:
https://resources.altium.com/p/your-guide-pcb-silkscreen
https://resources.pcb.cadence.com/blog/2022-essential-pcb-silkscreen-guidelines-for-layout

Vladmun1337, 2025-04-11:
Hello, I have tried my best to fix the issues about overlapping the routes. I have repositioned every name to avoid any routing along the board. Thank you!

Closed 2025-04-11.

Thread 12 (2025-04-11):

board misplacement

iTudy137, 2025-04-11:
The board is mounted incorrectly inside the case, causing misalignment with the ports and the buttons.

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

Vladmun1337, 2025-04-11:
Hello, I have realigned the board inside the enclosure. Thank you!

Closed 2025-04-11.

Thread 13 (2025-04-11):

battery misplacement

iTudy137, 2025-04-11:
Your battery is placed in the correct spot but upside-down. Please consider rotating it. It should face the top layer.

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

Vladmun1337, 2025-04-11:
Haha, thanks for the heads up! I flipped the battery and refitted it within the enclosure. Thank you!

Closed 2025-04-11.

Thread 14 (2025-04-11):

display misplacement

iTudy137, 2025-04-11:
Your display is positioned outside the enclosure. The connecting parts of it should be under the case and only the screen should be exposed.

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

Vladmun1337, 2025-04-11:
Hello, I have refitted the display. Thank you!

Closed 2025-04-11.

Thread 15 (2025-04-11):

screen texture

iTudy137, 2025-04-11:
Your screen layer from the display needs a different texture from the enclosure.

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

Vladmun1337, 2025-04-11:
For the given example I find it appropriate to keep the texture as is. It is for display purposes and material specifications are given to production. Thank you!

Closed 2025-04-11.

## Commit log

2025-04-06 Add hardware files
    [openbook.brd, openbook.sch]
2025-04-06 Add billing and gerber
    [PnP_Schematic_proiect v54_front.csv, Schematic_proiect v54.csv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]
2025-04-06 Add billing files
    [BOM.csv, PnP_front.csv]
2025-04-06 Add manufacturing
    [BOM.csv, PnP_front.csv]
2025-04-10 Fixed schematic issues
    [openbook.sch]
2025-04-10 Updated button positions, wire angles, allignment
    [openbook.brd]
2025-04-11 Fixed ground plane and silkscreen issues
    [openbook.brd]
2025-04-11 Modify layer of component names
    [openbook.brd]
2025-04-11 Update board render
2025-04-11 Add board image

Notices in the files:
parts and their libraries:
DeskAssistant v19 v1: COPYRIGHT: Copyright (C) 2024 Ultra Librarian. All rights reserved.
